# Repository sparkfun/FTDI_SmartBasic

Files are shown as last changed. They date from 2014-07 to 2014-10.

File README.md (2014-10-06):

FTDI_SmartBasic
===============
[FTDI SmartBasic  
*FTDI SmartBasic (DEV-12935)*](https://www.sparkfun.com/products/12935)

The FTDI SmartBasic uses a multiplexer to allow you to multiplex multiple serial 
devices into the hardware port on your Arduino Pro, Pro Mini, or other compatible 
board while still allowing you to program the board via the bootloader.

Repository Contents
-------------------
* **/Hardware** - All Eagle design files (.brd, .sch)
* **/Arduino** - All Arduino board examples
* **/Fritizing** - Fritzing part files
* **/Production** - Test bed files and production panel files

License Information
-------------------
The hardware is released under [Creative Commons Share-alike 3.0](http://creativecommons.org/licenses/by-sa/3.0/).  
All other code is open source so please feel free to do anything you want with it; yo

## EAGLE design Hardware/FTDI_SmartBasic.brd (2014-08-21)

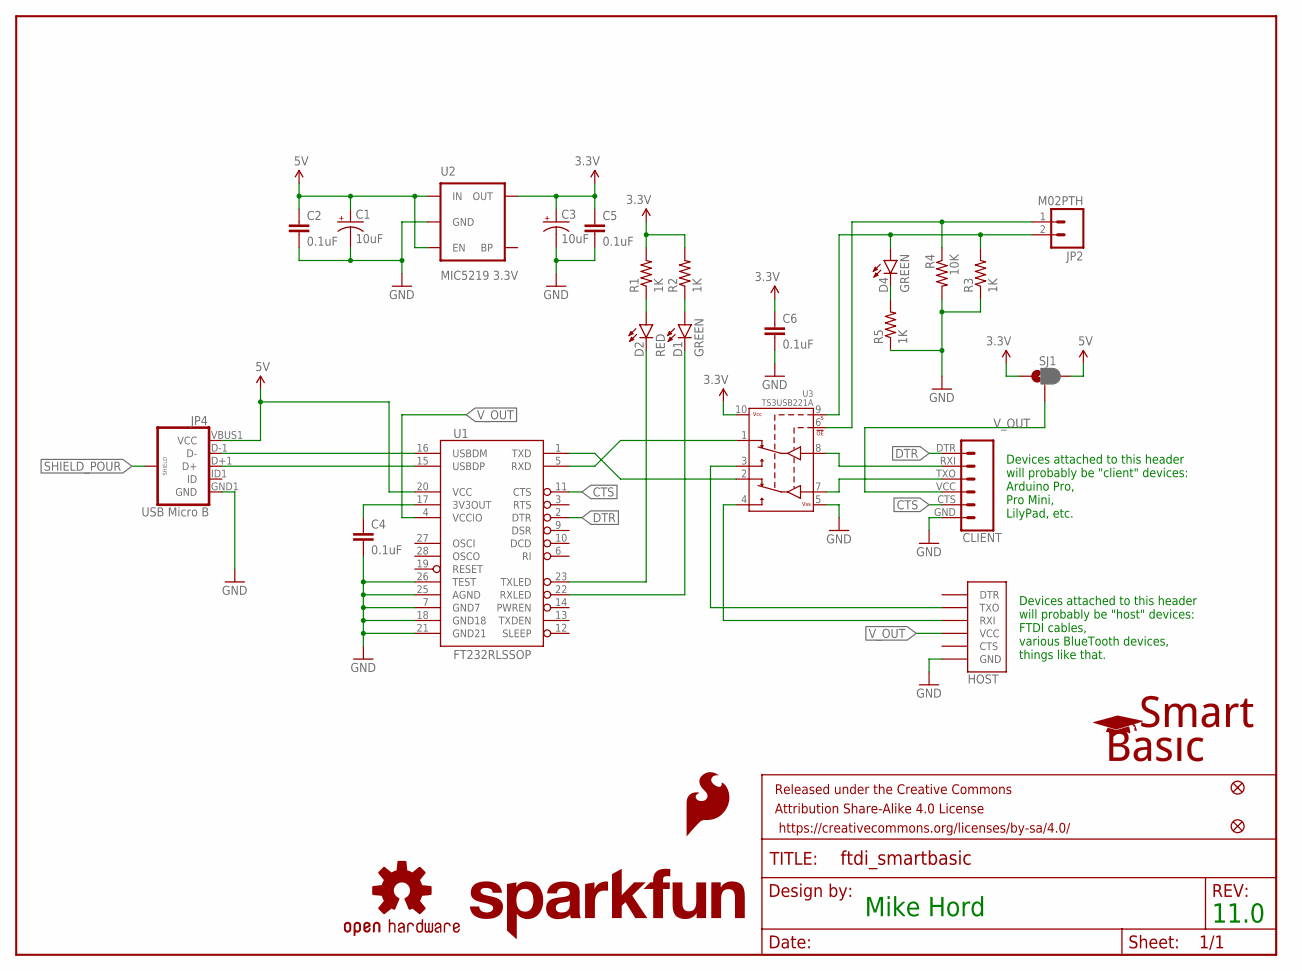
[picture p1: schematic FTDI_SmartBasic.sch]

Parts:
C1, C3: 10uF; EIA3216
C2, C4, C5, C6: 0.1uF; 0603-CAP
CLIENT: FTDI_BASICPTH; FTDI_BASIC
D1, D4: GREEN; LED-0603
D2: RED; LED-0603
FID1, FID2: FIDUCIAL1X2; FIDUCIAL-1X2
FRAME1: FRAME-LETTER; CREATIVE_COMMONS
HOST: FTDI_DEVICE; FTDI_DEVICE_SIDE
JP2: M02PTH; 1X02
JP4: USB Micro B; USB-B-MICRO-SMD_V03
LOGO1: SFE_LOGO_NAME.1_INCH; SFE_LOGO_NAME_.1
LOGO2: SFE_LOGO_FLAME.2_INCH; SFE_LOGO_FLAME_.2
LOGO3: OSHW-LOGOS; OSHW-LOGO-S
R1, R2, R3, R5: 1K; 0603-RES
R4: 10K; 0603-RES
SJ1: JUMPER-PAD-3-2OF3_NC_BY_PASTE; PAD-JUMPER-3-2OF3_NC_BY_PASTE_YES_SILK_FULL_BOX
U1: FT232RLSSOP; SSOP28DB
U2: MIC5219 3.3V; SOT23-5
U3: TS3USB221A; QFN-10-RSE
U$1: SMART_BASIC_LOGO

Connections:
3.3V: C3.A (+), C5.1, C6.1, R1.2, R2.2, SJ1.1, U2.5 (OUT), U3.10 (VCC)
5V: C1.A (+), C2.1, JP4.VBUS1 (VCC), SJ1.3, U1.20 (VCC), U2.1 (IN), U2.3 (EN)
!OE: JP2.1, R4.1, U3.6 (!OE)
CTS: CLIENT.CTS (5), U1.11 (CTS)
DTR: CLIENT.DTR (1), U1.2 (DTR)
GND: C1.C (-), C2.2, C3.C (-), C4.2, C5.2, C6.2, CLIENT.GND (6), HOST.P$6 (GND), JP4.GND1 (GND), R3.1, R4.2, R5.1, U1.7 (GND7), U1.18 (GND18), U1.21 (GND21), U1.25 (AGND), U1.26 (TEST), U2.2 (GND), U3.5 (VSS)
unnamed: JP4.D-1 (D-), U1.16 (USBDM)
unnamed: C4.1, U1.17 (3V3OUT)
unnamed: JP4.D+1 (D+), U1.15 (USBDP)
unnamed: D4.C, R5.2
unnamed: D2.A, R1.1
unnamed: D1.A, R2.1
unnamed: U1.5 (RXD), U3.1 (1D+)
unnamed: U1.1 (TXD), U3.2 (1D-)
unnamed: CLIENT.RXI (2), U3.8 (D+)
unnamed: CLIENT.TXO (3), U3.7 (D-)
unnamed: HOST.P$2 (TXO), U3.3 (2D+)
unnamed: HOST.P$3 (RXI), U3.4 (2D-)
RXLED: D1.C, U1.22 (RXLED)
SELECT: D4.A, JP2.2, R3.2, U3.9 (S)
SHIELD_POUR: JP4.SHIELD1 (SHIELD), JP4.SHIELD2 (SHIELD), JP4.SHIELD3 (SHIELD)
TXLED: D2.C, U1.23 (TXLED)
V_OUT: CLIENT.VCC (4), HOST.P$4 (VCC), SJ1.2, U1.4 (VCCIO)

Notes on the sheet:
Devices attached to this header will probably be "host" devices: FTDI cables, various BlueTooth devices, things like that.
Devices attached to this header will probably be "client" devices: Arduino Pro, Pro Mini, LilyPad, etc.
Mike Hord
11.0

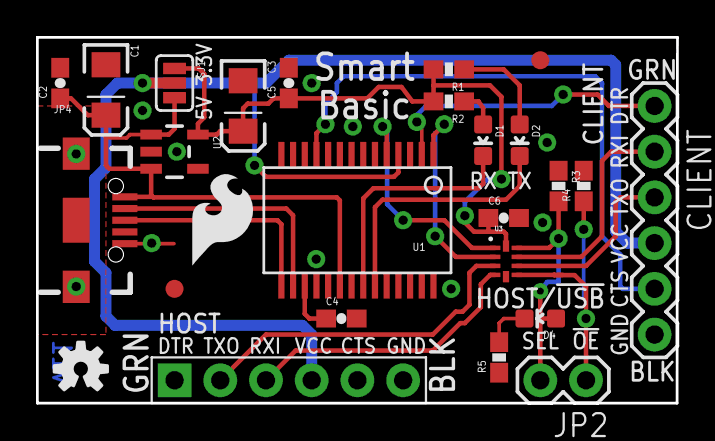
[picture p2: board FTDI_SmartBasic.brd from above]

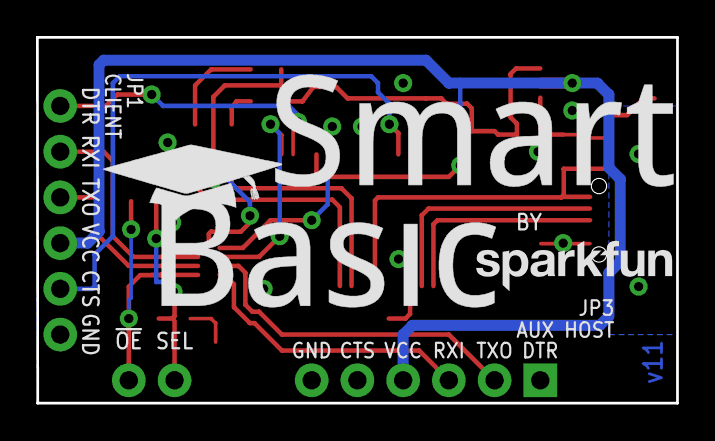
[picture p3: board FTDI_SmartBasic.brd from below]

Board: 2 copper layers, 35.6 x 20.3 mm, 29 parts (2 on the bottom side), 23 nets.

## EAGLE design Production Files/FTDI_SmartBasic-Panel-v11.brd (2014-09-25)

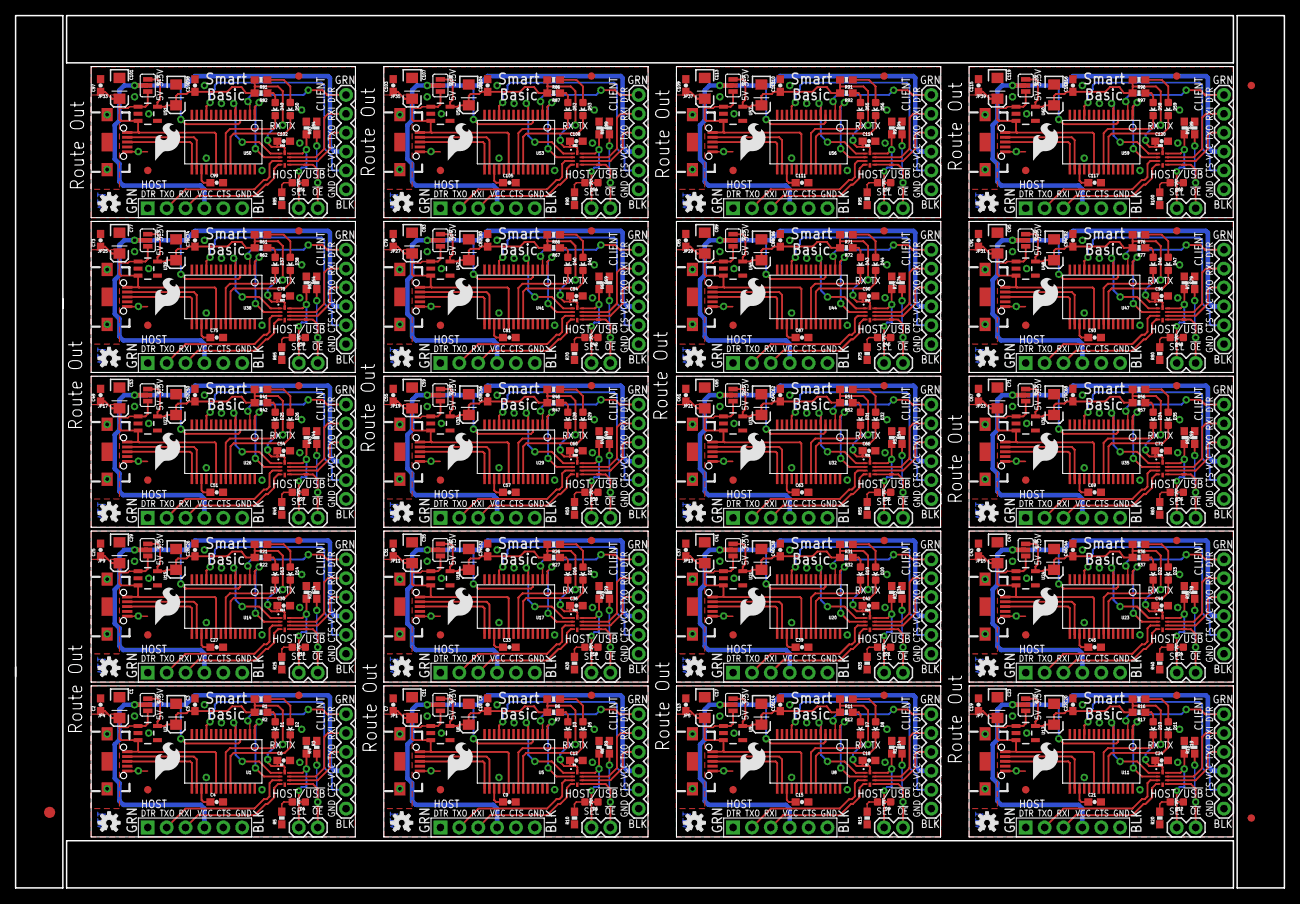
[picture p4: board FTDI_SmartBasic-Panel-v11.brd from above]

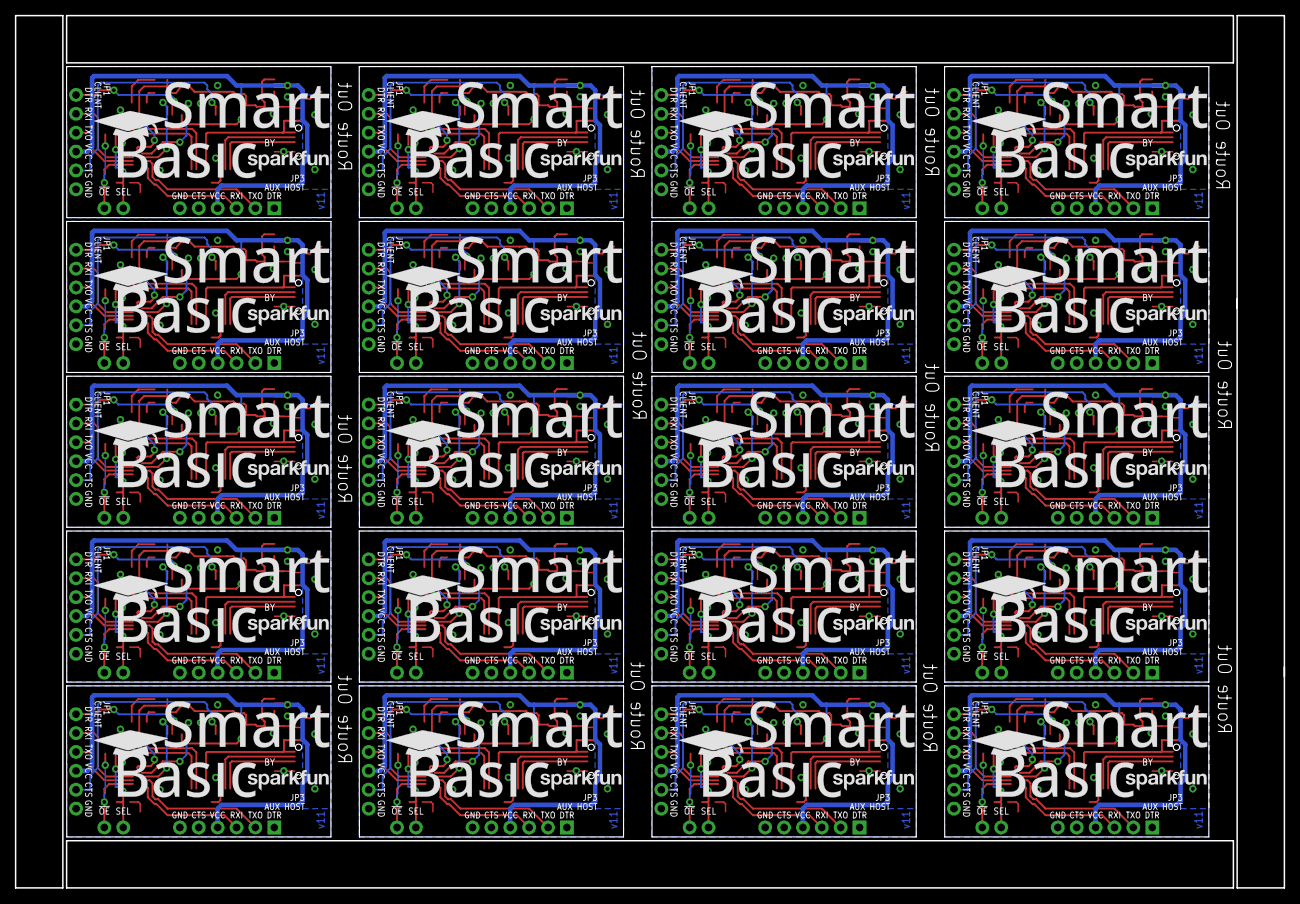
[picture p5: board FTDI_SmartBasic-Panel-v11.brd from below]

Board: 2 copper layers, 170.7 x 117.3 mm, 563 parts (40 on the bottom side), 460 nets.

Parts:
C1, C3, C8, C11, C14, C17, C20, C23, C26, C29, C32, C35, C38, C41, C44, C47, C50, C53, C56, C59, C62, C65, C68, C71, C74, C77, C80, C83, C86, C89, C92, C95, C98, C101, C104, C107, C110, C113, C116, C119: 10uF; EIA3216
C2, C4, C5, C6, C7, C9, C10, C12, C13, C15, C16, C18, C19, C21, C22, C24, C25, C27, C28, C30, C31, C33, C34, C36, C37, C39, C40, C42, C43, C45, C46, C48, C49, C51, C52, C54, C55, C57, C58, C60, C61, C63, C64, C66, C67, C69, C70, C72, C73, C75, C76, C78, C79, C81, C82, C84, C85, C87, C88, C90, C91, C93, C94, C96, C97, C99, C100, C102, C103, C105, C106, C108, C109, C111, C112, C114, C115, C117, C118, C120: 0.1uF; 0603-CAP
CLIENT, CLIENT1, CLIENT2, CLIENT3, CLIENT4, CLIENT5, CLIENT6, CLIENT7, CLIENT8, CLIENT9, CLIENT10, CLIENT11, CLIENT12, CLIENT13, CLIENT14, CLIENT15, CLIENT16, CLIENT17, CLIENT18, CLIENT19: FTDI_BASIC
D1, D3, D4, D6, D7, D9, D10, D12, D13, D15, D16, D18, D19, D21, D22, D24, D25, D27, D28, D30, D31, D33, D34, D36, D37, D39, D40, D42, D43, D45, D46, D48, D49, D51, D52, D54, D55, D57, D58, D60: GREEN; LED-0603
D2, D5, D8, D11, D14, D17, D20, D23, D26, D29, D32, D35, D38, D41, D44, D47, D50, D53, D56, D59: RED; LED-0603
E$1: FIDUCIAL-1.5X3
E$5, E$7: FIDUCIAL-1X2
FID1, FID2, FID3, FID4, FID5, FID6, FID7, FID8, FID9, FID10, FID11, FID12, FID13, FID14, FID15, FID16, FID17, FID18, FID19, FID20, FID21, FID22, FID23, FID24, FID25, FID26, FID27, FID28, FID29, FID30, FID31, FID32, FID33, FID34, FID35, FID36, FID37, FID38, FID39, FID40: FIDUCIAL1X2; FIDUCIAL-1X2
HOST, HOST1, HOST2, HOST3, HOST4, HOST5, HOST6, HOST7, HOST8, HOST9, HOST10, HOST11, HOST12, HOST13, HOST14, HOST15, HOST16, HOST17, HOST18, HOST19: FTDI_DEVICE_SIDE
JP1, JP4, JP5, JP7, JP9, JP11, JP13, JP15, JP17, JP19, JP21, JP23, JP25, JP27, JP29, JP31, JP33, JP35, JP37, JP39: USB Micro B; USB-B-MICRO-SMD_V03
JP2, JP3, JP6, JP8, JP10, JP12, JP14, JP16, JP18, JP20, JP22, JP24, JP26, JP28, JP30, JP32, JP34, JP36, JP38, JP40: M02PTH; 1X02
LOGO1, LOGO4, LOGO7, LOGO10, LOGO13, LOGO16, LOGO19, LOGO22, LOGO25, LOGO28, LOGO31, LOGO34, LOGO37, LOGO40, LOGO43, LOGO46, LOGO49, LOGO52, LOGO55, LOGO58: SFE_LOGO_NAME.1_INCH; SFE_LOGO_NAME_.1
LOGO2, LOGO6, LOGO9, LOGO12, LOGO15, LOGO18, LOGO21, LOGO24, LOGO27, LOGO30, LOGO33, LOGO36, LOGO39, LOGO42, LOGO45, LOGO48, LOGO51, LOGO54, LOGO57, LOGO60: SFE_LOGO_FLAME.2_INCH; SFE_LOGO_FLAME_.2
LOGO3, LOGO5, LOGO8, LOGO11, LOGO14, LOGO17, LOGO20, LOGO23, LOGO26, LOGO29, LOGO32, LOGO35, LOGO38, LOGO41, LOGO44, LOGO47, LOGO50, LOGO53, LOGO56, LOGO59: OSHW-LOGOS; OSHW-LOGO-S
R1, R2, R3, R5, R6, R7, R9, R10, R11, R12, R14, R15, R16, R17, R19, R20, R21, R22, R24, R25, R26, R27, R29, R30, R31, R32, R34, R35, R36, R37, R39, R40, R41, R42, R44, R45, R46, R47, R49, R50, R51, R52, R54, R55, R56, R57, R59, R60, R61, R62, R64, R65, R66, R67, R69, R70, R71, R72, R74, R75, R76, R77, R79, R80, R81, R82, R84, R85, R86, R87, R89, R90, R91, R92, R94, R95, R96, R97, R99, R100: 1K; 0603-RES
R4, R8, R13, R18, R23, R28, R33, R38, R43, R48, R53, R58, R63, R68, R73, R78, R83, R88, R93, R98: 10K; 0603-RES
SJ1, SJ2, SJ3, SJ4, SJ5, SJ6, SJ7, SJ8, SJ9, SJ10, SJ11, SJ12, SJ13, SJ14, SJ15, SJ16, SJ17, SJ18, SJ19, SJ20: JUMPER-PAD-3-2OF3_NC_BY_PASTE; PAD-JUMPER-3-2OF3_NC_BY_PASTE_YES_SILK_FULL_BOX
U1, U5, U8, U11, U14, U17, U20, U23, U26, U29, U32, U35, U38, U41, U44, U47, U50, U53, U56, U59: FT232RLSSOP; SSOP28DB
U2, U6, U9, U12, U15, U18, U21, U24, U27, U30, U33, U36, U39, U42, U45, U48, U51, U54, U57, U60: MIC5219 3.3V; SOT23-5
U3, U4, U7, U10, U13, U16, U19, U22, U25, U28, U31, U34, U37, U40, U43, U46, U49, U52, U55, U58: TS3USB221A; QFN-10-RSE
U$1, U$2, U$3, U$4, U$5, U$6, U$7, U$8, U$9, U$10, U$11, U$12, U$13, U$14, U$15, U$16, U$17, U$18, U$19, U$20: SMART_BASIC_LOGO

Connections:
3.3V: C3.A, C5.1, C6.1, R1.2, R2.2, SJ1.1, U2.5, U3.10
3.3V1: C8.A, C10.1, C12.1, R6.2, R7.2, SJ2.1, U4.10, U6.5
3.3V2: C14.A, C16.1, C18.1, R11.2, R12.2, SJ3.1, U7.10, U9.5
3.3V3: C20.A, C22.1, C24.1, R16.2, R17.2, SJ4.1, U10.10, U12.5
3.3V4: C26.A, C28.1, C30.1, R21.2, R22.2, SJ5.1, U13.10, U15.5
3.3V5: C32.A, C34.1, C36.1, R26.2, R27.2, SJ6.1, U16.10, U18.5
3.3V6: C38.A, C40.1, C42.1, R31.2, R32.2, SJ7.1, U19.10, U21.5
3.3V7: C44.A, C46.1, C48.1, R36.2, R37.2, SJ8.1, U22.10, U24.5
3.3V8: C50.A, C52.1, C54.1, R41.2, R42.2, SJ9.1, U25.10, U27.5
3.3V9: C56.A, C58.1, C60.1, R46.2, R47.2, SJ10.1, U28.10, U30.5
3.3V10: C62.A, C64.1, C66.1, R51.2, R52.2, SJ11.1, U31.10, U33.5
3.3V11: C68.A, C70.1, C72.1, R56.2, R57.2, SJ12.1, U34.10, U36.5
3.3V12: C74.A, C76.1, C78.1, R61.2, R62.2, SJ13.1, U37.10, U39.5
3.3V13: C80.A, C82.1, C84.1, R66.2, R67.2, SJ14.1, U40.10, U42.5
3.3V14: C86.A, C88.1, C90.1, R71.2, R72.2, SJ15.1, U43.10, U45.5
3.3V15: C92.A, C94.1, C96.1, R76.2, R77.2, SJ16.1, U46.10, U48.5
3.3V16: C98.A, C100.1, C102.1, R81.2, R82.2, SJ17.1, U49.10, U51.5
3.3V17: C104.A, C106.1, C108.1, R86.2, R87.2, SJ18.1, U52.10, U54.5
3.3V18: C110.A, C112.1, C114.1, R91.2, R92.2, SJ19.1, U55.10, U57.5
3.3V19: C116.A, C118.1, C120.1, R96.2, R97.2, SJ20.1, U58.10, U60.5
5V: C1.A, C2.1, JP4.VBUS1, SJ1.3, U1.20, U2.1, U2.3
5V1: C7.1, C11.A, JP1.VBUS1, SJ2.3, U5.20, U6.1, U6.3
5V2: C13.1, C17.A, JP5.VBUS1, SJ3.3, U8.20, U9.1, U9.3
5V3: C19.1, C23.A, JP7.VBUS1, SJ4.3, U11.20, U12.1, U12.3
5V4: C25.1, C29.A, JP9.VBUS1, SJ5.3, U14.20, U15.1, U15.3
5V5: C31.1, C35.A, JP11.VBUS1, SJ6.3, U17.20, U18.1, U18.3
5V6: C37.1, C41.A, JP13.VBUS1, SJ7.3, U20.20, U21.1, U21.3
5V7: C43.1, C47.A, JP15.VBUS1, SJ8.3, U23.20, U24.1, U24.3
5V8: C49.1, C53.A, JP17.VBUS1, SJ9.3, U26.20, U27.1, U27.3
5V9: C55.1, C59.A, JP19.VBUS1, SJ10.3, U29.20, U30.1, U30.3
5V10: C61.1, C65.A, JP21.VBUS1, SJ11.3, U32.20, U33.1, U33.3
5V11: C67.1, C71.A, JP23.VBUS1, SJ12.3, U35.20, U36.1, U36.3
5V12: C73.1, C77.A, JP25.VBUS1, SJ13.3, U38.20, U39.1, U39.3
5V13: C79.1, C83.A, JP27.VBUS1, SJ14.3, U41.20, U42.1, U42.3
5V14: C85.1, C89.A, JP29.VBUS1, SJ15.3, U44.20, U45.1, U45.3
5V15: C91.1, C95.A, JP31.VBUS1, SJ16.3, U47.20, U48.1, U48.3
5V16: C97.1, C101.A, JP33.VBUS1, SJ17.3, U50.20, U51.1, U51.3
5V17: C103.1, C107.A, JP35.VBUS1, SJ18.3, U53.20, U54.1, U54.3
5V18: C109.1, C113.A, JP37.VBUS1, SJ19.3, U56.20, U57.1, U57.3
5V19: C115.1, C119.A, JP39.VBUS1, SJ20.3, U59.20, U60.1, U60.3
!OE: JP2.1, R4.1, U3.6
!OE1: JP3.1, R8.1, U4.6
!OE2: JP6.1, R13.1, U7.6
!OE3: JP8.1, R18.1, U10.6
!OE4: JP10.1, R23.1, U13.6
!OE5: JP12.1, R28.1, U16.6
!OE6: JP14.1, R33.1, U19.6
!OE7: JP16.1, R38.1, U22.6
!OE8: JP18.1, R43.1, U25.6
!OE9: JP20.1, R48.1, U28.6
!OE10: JP22.1, R53.1, U31.6
!OE11: JP24.1, R58.1, U34.6
!OE12: JP26.1, R63.1, U37.6
!OE13: JP28.1, R68.1, U40.6
!OE14: JP30.1, R73.1, U43.6
!OE15: JP32.1, R78.1, U46.6
!OE16: JP34.1, R83.1, U49.6
!OE17: JP36.1, R88.1, U52.6
!OE18: JP38.1, R93.1, U55.6
!OE19: JP40.1, R98.1, U58.6
CTS: CLIENT.CTS, U1.11
CTS1: CLIENT1.CTS, U5.11
CTS2: CLIENT2.CTS, U8.11
CTS3: CLIENT3.CTS, U11.11
CTS4: CLIENT4.CTS, U14.11
CTS5: CLIENT5.CTS, U17.11
CTS6: CLIENT6.CTS, U20.11
CTS7: CLIENT7.CTS, U23.11
CTS8: CLIENT8.CTS, U26.11
CTS9: CLIENT9.CTS, U29.11
CTS10: CLIENT10.CTS, U32.11
CTS11: CLIENT11.CTS, U35.11
CTS12: CLIENT12.CTS, U38.11
CTS13: CLIENT13.CTS, U41.11
CTS14: CLIENT14.CTS, U44.11
CTS15: CLIENT15.CTS, U47.11
CTS16: CLIENT16.CTS, U50.11
CTS17: CLIENT17.CTS, U53.11
CTS18: CLIENT18.CTS, U56.11
CTS19: CLIENT19.CTS, U59.11
DTR: CLIENT.DTR, U1.2
DTR1: CLIENT1.DTR, U5.2
DTR2: CLIENT2.DTR, U8.2
DTR3: CLIENT3.DTR, U11.2
DTR4: CLIENT4.DTR, U14.2
DTR5: CLIENT5.DTR, U17.2
DTR6: CLIENT6.DTR, U20.2
DTR7: CLIENT7.DTR, U23.2
DTR8: CLIENT8.DTR, U26.2
DTR9: CLIENT9.DTR, U29.2
DTR10: CLIENT10.DTR, U32.2
DTR11: CLIENT11.DTR, U35.2
DTR12: CLIENT12.DTR, U38.2
DTR13: CLIENT13.DTR, U41.2
DTR14: CLIENT14.DTR, U44.2
DTR15: CLIENT15.DTR, U47.2
DTR16: CLIENT16.DTR, U50.2
DTR17: CLIENT17.DTR, U53.2
DTR18: CLIENT18.DTR, U56.2
DTR19: CLIENT19.DTR, U59.2
GND: C1.C, C2.2, C3.C, C4.2, C5.2, C6.2, CLIENT.GND, HOST.P$6, JP4.GND1, R3.1, R4.2, R5.1, U1.7, U1.18, U1.21, U1.25, U1.26, U2.2, U3.5
GND1: C7.2, C8.C, C9.2, C10.2, C11.C, C12.2, CLIENT1.GND, HOST1.P$6, JP1.GND1, R8.2, R9.1, R10.1, U4.5, U5.7, U5.18, U5.21, U5.25, U5.26, U6.2
GND2: C13.2, C14.C, C15.2, C16.2, C17.C, C18.2, CLIENT2.GND, HOST2.P$6, JP5.GND1, R13.2, R14.1, R15.1, U7.5, U8.7, U8.18, U8.21, U8.25, U8.26, U9.2
GND3: C19.2, C20.C, C21.2, C22.2, C23.C, C24.2, CLIENT3.GND, HOST3.P$6, JP7.GND1, R18.2, R19.1, R20.1, U10.5, U11.7, U11.18, U11.21, U11.25, U11.26, U12.2
GND4: C25.2, C26.C, C27.2, C28.2, C29.C, C30.2, CLIENT4.GND, HOST4.P$6, JP9.GND1, R23.2, R24.1, R25.1, U13.5, U14.7, U14.18, U14.21, U14.25, U14.26, U15.2
GND5: C31.2, C32.C, C33.2, C34.2, C35.C, C36.2, CLIENT5.GND, HOST5.P$6, JP11.GND1, R28.2, R29.1, R30.1, U16.5, U17.7, U17.18, U17.21, U17.25, U17.26, U18.2
GND6: C37.2, C38.C, C39.2, C40.2, C41.C, C42.2, CLIENT6.GND, HOST6.P$6, JP13.GND1, R33.2, R34.1, R35.1, U19.5, U20.7, U20.18, U20.21, U20.25, U20.26, U21.2
GND7: C43.2, C44.C, C45.2, C46.2, C47.C, C48.2, CLIENT7.GND, HOST7.P$6, JP15.GND1, R38.2, R39.1, R40.1, U22.5, U23.7, U23.18, U23.21, U23.25, U23.26, U24.2
GND8: C49.2, C50.C, C51.2, C52.2, C53.C, C54.2, CLIENT8.GND, HOST8.P$6, JP17.GND1, R43.2, R44.1, R45.1, U25.5, U26.7, U26.18, U26.21, U26.25, U26.26, U27.2
GND9: C55.2, C56.C, C57.2, C58.2, C59.C, C60.2, CLIENT9.GND, HOST9.P$6, JP19.GND1, R48.2, R49.1, R50.1, U28.5, U29.7, U29.18, U29.21, U29.25, U29.26, U30.2
GND10: C61.2, C62.C, C63.2, C64.2, C65.C, C66.2, CLIENT10.GND, HOST10.P$6, JP21.GND1, R53.2, R54.1, R55.1, U31.5, U32.7, U32.18, U32.21, U32.25, U32.26, U33.2
GND11: C67.2, C68.C, C69.2, C70.2, C71.C, C72.2, CLIENT11.GND, HOST11.P$6, JP23.GND1, R58.2, R59.1, R60.1, U34.5, U35.7, U35.18, U35.21, U35.25, U35.26, U36.2
GND12: C73.2, C74.C, C75.2, C76.2, C77.C, C78.2, CLIENT12.GND, HOST12.P$6, JP25.GND1, R63.2, R64.1, R65.1, U37.5, U38.7, U38.18, U38.21, U38.25, U38.26, U39.2
GND13: C79.2, C80.C, C81.2, C82.2, C83.C, C84.2, CLIENT13.GND, HOST13.P$6, JP27.GND1, R68.2, R69.1, R70.1, U40.5, U41.7, U41.18, U41.21, U41.25, U41.26, U42.2
GND14: C85.2, C86.C, C87.2, C88.2, C89.C, C90.2, CLIENT14.GND, HOST14.P$6, JP29.GND1, R73.2, R74.1, R75.1, U43.5, U44.7, U44.18, U44.21, U44.25, U44.26, U45.2
GND15: C91.2, C92.C, C93.2, C94.2, C95.C, C96.2, CLIENT15.GND, HOST15.P$6, JP31.GND1, R78.2, R79.1, R80.1, U46.5, U47.7, U47.18, U47.21, U47.25, U47.26, U48.2
GND16: C97.2, C98.C, C99.2, C100.2, C101.C, C102.2, CLIENT16.GND, HOST16.P$6, JP33.GND1, R83.2, R84.1, R85.1, U49.5, U50.7, U50.18, U50.21, U50.25, U50.26, U51.2
GND17: C103.2, C104.C, C105.2, C106.2, C107.C, C108.2, CLIENT17.GND, HOST17.P$6, JP35.GND1, R88.2, R89.1, R90.1, U52.5, U53.7, U53.18, U53.21, U53.25, U53.26, U54.2
GND18: C109.2, C110.C, C111.2, C112.2, C113.C, C114.2, CLIENT18.GND, HOST18.P$6, JP37.GND1, R93.2, R94.1, R95.1, U55.5, U56.7, U56.18, U56.21, U56.25, U56.26, U57.2
GND19: C115.2, C116.C, C117.2, C118.2, C119.C, C120.2, CLIENT19.GND, HOST19.P$6, JP39.GND1, R98.2, R99.1, R100.1, U58.5, U59.7, U59.18, U59.21, U59.25, U59.26, U60.2
unnamed: JP4.D-1, U1.16
unnamed: C4.1, U1.17
unnamed: JP4.D+1, U1.15
unnamed: D4.C, R5.2
unnamed: D2.A, R1.1
unnamed: D1.A, R2.1
unnamed: JP1.D-1, U5.16
unnamed: JP1.D+1, U5.15
unnamed: D5.A, R6.1
unnamed: D3.A, R7.1
unnamed: U1.5, U3.1
unnamed: U1.1, U3.2
unnamed: CLIENT.RXI, U3.8
unnamed: CLIENT.TXO, U3.7
unnamed: CLIENT1.RXI, U4.8
unnamed: HOST.P$2, U3.3
unnamed: HOST.P$3, U3.4
unnamed: CLIENT1.TXO, U4.7
unnamed: U4.1, U5.5
unnamed: U4.2, U5.1
unnamed: HOST1.P$2, U4.3
unnamed: HOST1.P$3, U4.4
unnamed: C9.1, U5.17
unnamed: D6.C, R10.2
unnamed: JP5.D-1, U8.16
unnamed: JP5.D+1, U8.15
unnamed: D8.A, R11.1
unnamed: D7.A, R12.1
unnamed: CLIENT2.RXI, U7.8
unnamed: CLIENT2.TXO, U7.7
unnamed: U7.1, U8.5
unnamed: U7.2, U8.1
unnamed: HOST2.P$2, U7.3
unnamed: HOST2.P$3, U7.4
unnamed: C15.1, U8.17
unnamed: D9.C, R15.2
unnamed: JP7.D-1, U11.16
unnamed: JP7.D+1, U11.15
unnamed: D11.A, R16.1
unnamed: D10.A, R17.1
unnamed: CLIENT3.RXI, U10.8
unnamed: CLIENT3.TXO, U10.7
unnamed: U10.1, U11.5
unnamed: U10.2, U11.1
unnamed: HOST3.P$2, U10.3
unnamed: HOST3.P$3, U10.4
unnamed: C21.1, U11.17
unnamed: D12.C, R20.2
unnamed: JP9.D-1, U14.16
unnamed: JP9.D+1, U14.15
unnamed: D14.A, R21.1
unnamed: D13.A, R22.1
unnamed: CLIENT4.RXI, U13.8
unnamed: CLIENT4.TXO, U13.7
unnamed: U13.1, U14.5
unnamed: U13.2, U14.1
unnamed: HOST4.P$2, U13.3
unnamed: HOST4.P$3, U13.4
unnamed: C27.1, U14.17
unnamed: D15.C, R25.2
unnamed: JP11.D-1, U17.16
unnamed: JP11.D+1, U17.15
unnamed: D17.A, R26.1
unnamed: D16.A, R27.1
unnamed: CLIENT5.RXI, U16.8
unnamed: CLIENT5.TXO, U16.7
unnamed: U16.1, U17.5
unnamed: U16.2, U17.1
unnamed: HOST5.P$2, U16.3
unnamed: HOST5.P$3, U16.4
unnamed: C33.1, U17.17
unnamed: D18.C, R30.2
unnamed: JP13.D-1, U20.16
unnamed: JP13.D+1, U20.15
unnamed: D20.A, R31.1
unnamed: D19.A, R32.1
unnamed: CLIENT6.RXI, U19.8
unnamed: CLIENT6.TXO, U19.7
unnamed: U19.1, U20.5
unnamed: U19.2, U20.1
unnamed: HOST6.P$2, U19.3
unnamed: HOST6.P$3, U19.4
unnamed: C39.1, U20.17
unnamed: D21.C, R35.2
unnamed: JP15.D-1, U23.16
unnamed: JP15.D+1, U23.15
unnamed: D23.A, R36.1
unnamed: D22.A, R37.1
unnamed: CLIENT7.RXI, U22.8
unnamed: CLIENT7.TXO, U22.7
unnamed: U22.1, U23.5
unnamed: U22.2, U23.1
unnamed: HOST7.P$2, U22.3
unnamed: HOST7.P$3, U22.4
unnamed: C45.1, U23.17
unnamed: D24.C, R40.2
unnamed: JP17.D-1, U26.16
unnamed: JP17.D+1, U26.15
unnamed: D26.A, R41.1
unnamed: D25.A, R42.1
unnamed: CLIENT8.RXI, U25.8
unnamed: CLIENT8.TXO, U25.7
unnamed: U25.1, U26.5
unnamed: U25.2, U26.1
unnamed: HOST8.P$2, U25.3
unnamed: HOST8.P$3, U25.4
unnamed: C51.1, U26.17
unnamed: D27.C, R45.2
unnamed: JP19.D-1, U29.16
unnamed: JP19.D+1, U29.15
unnamed: D29.A, R46.1
unnamed: D28.A, R47.1
unnamed: CLIENT9.RXI, U28.8
unnamed: CLIENT9.TXO, U28.7
unnamed: U28.1, U29.5
unnamed: U28.2, U29.1
unnamed: HOST9.P$2, U28.3
unnamed: HOST9.P$3, U28.4
unnamed: C57.1, U29.17
unnamed: D30.C, R50.2
unnamed: JP21.D-1, U32.16
unnamed: JP21.D+1, U32.15
unnamed: D32.A, R51.1
unnamed: D31.A, R52.1
unnamed: CLIENT10.RXI, U31.8
unnamed: CLIENT10.TXO, U31.7
unnamed: U31.1, U32.5
unnamed: U31.2, U32.1
unnamed: HOST10.P$2, U31.3
unnamed: HOST10.P$3, U31.4
unnamed: C63.1, U32.17
unnamed: D33.C, R55.2
unnamed: JP23.D-1, U35.16
unnamed: JP23.D+1, U35.15
unnamed: D35.A, R56.1
unnamed: D34.A, R57.1
unnamed: CLIENT11.RXI, U34.8
unnamed: CLIENT11.TXO, U34.7
unnamed: U34.1, U35.5
unnamed: U34.2, U35.1
unnamed: HOST11.P$2, U34.3
unnamed: HOST11.P$3, U34.4
unnamed: C69.1, U35.17
unnamed: D36.C, R60.2
unnamed: JP25.D-1, U38.16
unnamed: JP25.D+1, U38.15
unnamed: D38.A, R61.1
unnamed: D37.A, R62.1
unnamed: CLIENT12.RXI, U37.8
unnamed: CLIENT12.TXO, U37.7
unnamed: U37.1, U38.5
unnamed: U37.2, U38.1
unnamed: HOST12.P$2, U37.3
unnamed: HOST12.P$3, U37.4
unnamed: C75.1, U38.17
unnamed: D39.C, R65.2
unnamed: JP27.D-1, U41.16
unnamed: JP27.D+1, U41.15
unnamed: D41.A, R66.1
unnamed: D40.A, R67.1
unnamed: CLIENT13.RXI, U40.8
unnamed: CLIENT13.TXO, U40.7
unnamed: U40.1, U41.5
unnamed: U40.2, U41.1
unnamed: HOST13.P$2, U40.3
unnamed: HOST13.P$3, U40.4
unnamed: C81.1, U41.17
unnamed: D42.C, R70.2
unnamed: JP29.D-1, U44.16
unnamed: JP29.D+1, U44.15
unnamed: D44.A, R71.1
unnamed: D43.A, R72.1
unnamed: CLIENT14.RXI, U43.8
unnamed: CLIENT14.TXO, U43.7
unnamed: U43.1, U44.5
unnamed: U43.2, U44.1
unnamed: HOST14.P$2, U43.3
unnamed: HOST14.P$3, U43.4
unnamed: C87.1, U44.17
unnamed: D45.C, R75.2
unnamed: JP31.D-1, U47.16
unnamed: JP31.D+1, U47.15
unnamed: D47.A, R76.1
unnamed: D46.A, R77.1
unnamed: CLIENT15.RXI, U46.8
unnamed: CLIENT15.TXO, U46.7
unnamed: U46.1, U47.5
unnamed: U46.2, U47.1
unnamed: HOST15.P$2, U46.3
unnamed: HOST15.P$3, U46.4
unnamed: C93.1, U47.17
unnamed: D48.C, R80.2
unnamed: JP33.D-1, U50.16
unnamed: JP33.D+1, U50.15
unnamed: D50.A, R81.1
unnamed: D49.A, R82.1
unnamed: CLIENT16.RXI, U49.8
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

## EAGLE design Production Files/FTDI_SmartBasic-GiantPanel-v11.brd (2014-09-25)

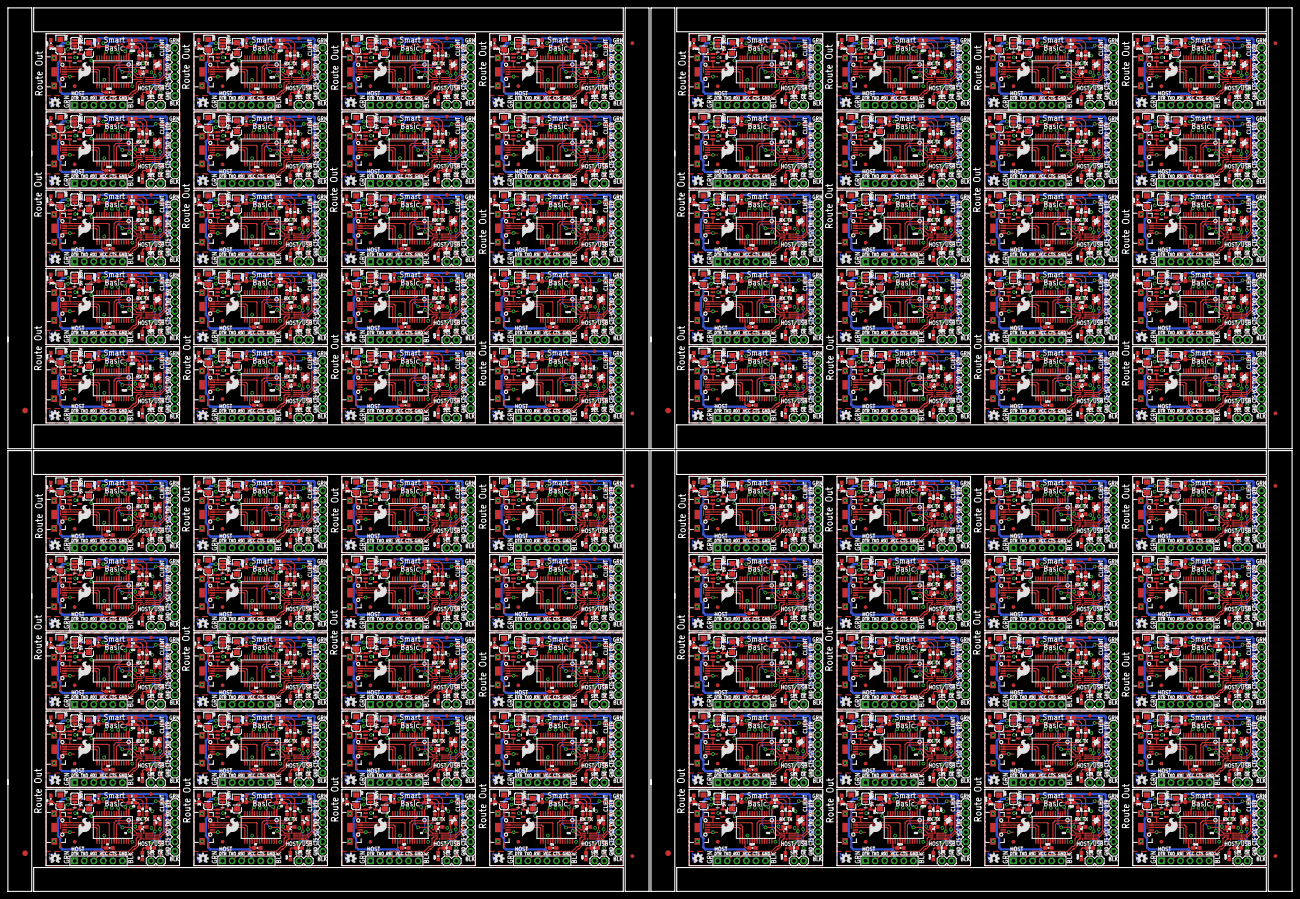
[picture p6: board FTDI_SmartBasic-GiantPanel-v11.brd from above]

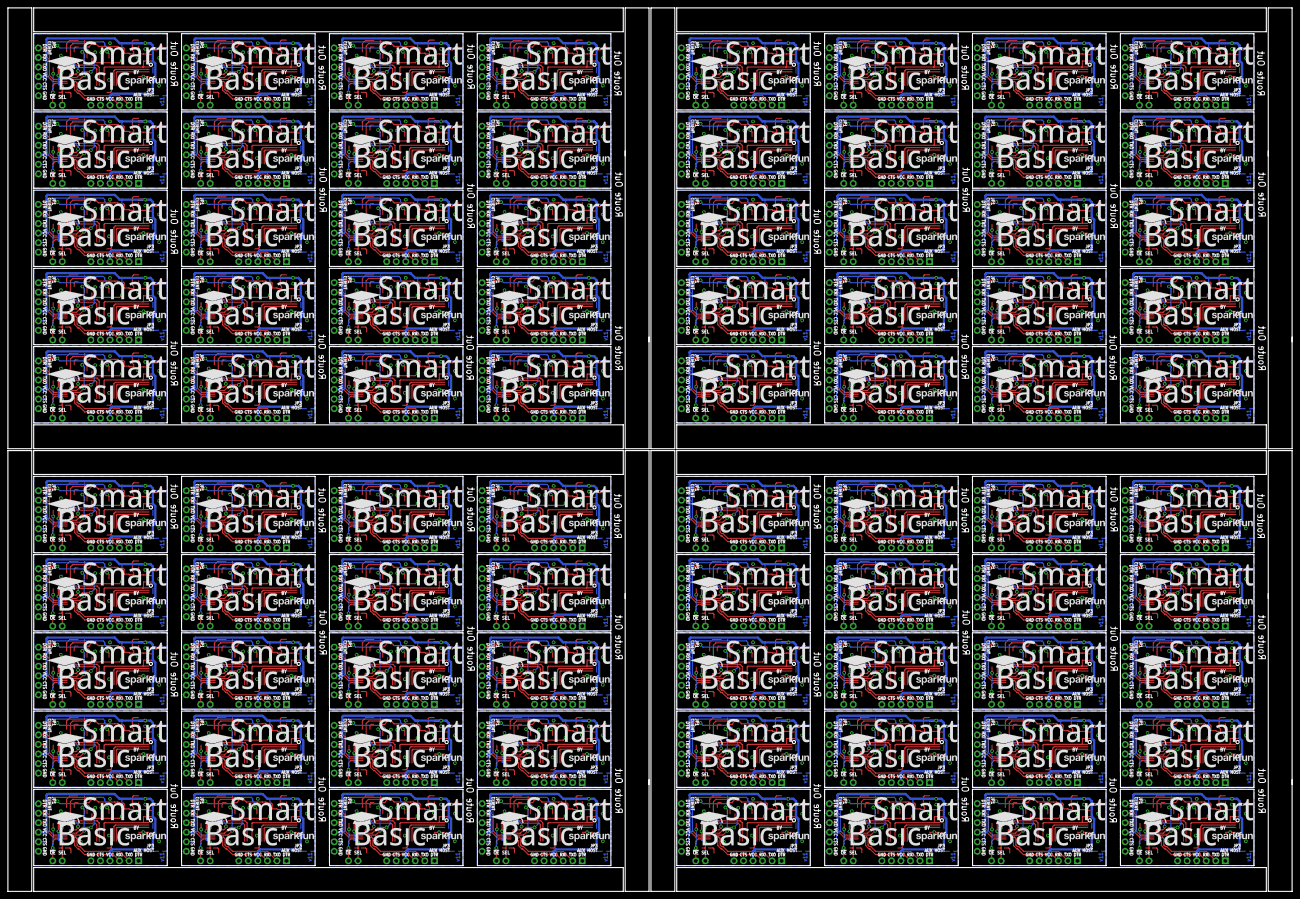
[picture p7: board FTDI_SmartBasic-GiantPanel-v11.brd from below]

Board: 2 copper layers, 341.9 x 235.2 mm, 2252 parts (160 on the bottom side), 1840 nets.

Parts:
C1, C3, C8, C11, C14, C17, C20, C23, C26, C29, C32, C35, C38, C41, C44, C47, C50, C53, C56, C59, C62, C65, C68, C71, C74, C77, C80, C83, C86, C89, C92, C95, C98, C101, C104, C107, C110, C113, C116, C119, C122, C125, C128, C131, C134, C137, C140, C143, C146, C149, C152, C155, C158, C161, C164, C167, C170, C173, C176, C179, C182, C185, C188, C191, C194, C197, C200, C203, C206, C209, C212, C215, C218, C221, C224, C227, C230, C233, C236, C239, C242, C245, C248, C251, C254, C257, C260, C263, C266, C269, C272, C275, C278, C281, C284, C287, C290, C293, C296, C299, C302, C305, C308, C311, C314, C317, C320, C323, C326, C329, C332, C335, C338, C341, C344, C347, C350, C353, C356, C359, C362, C365, C368, C371, C374, C377, C380, C383, C386, C389, C392, C395, C398, C401, C404, C407, C410, C413, C416, C419, C422, C425, C428, C431, C434, C437, C440, C443, C446, C449, C452, C455, C458, C461, C464, C467, C470, C473, C476, C479: 10uF; EIA3216
C2, C4, C5, C6, C7, C9, C10, C12, C13, C15, C16, C18, C19, C21, C22, C24, C25, C27, C28, C30, C31, C33, C34, C36, C37, C39, C40, C42, C43, C45, C46, C48, C49, C51, C52, C54, C55, C57, C58, C60, C61, C63, C64, C66, C67, C69, C70, C72, C73, C75, C76, C78, C79, C81, C82, C84, C85, C87, C88, C90, C91, C93, C94, C96, C97, C99, C100, C102, C103, C105, C106, C108, C109, C111, C112, C114, C115, C117, C118, C120, C121, C123, C124, C126, C127, C129, C130, C132, C133, C135, C136, C138, C139, C141, C142, C144, C145, C147, C148, C150, C151, C153, C154, C156, C157, C159, C160, C162, C163, C165, C166, C168, C169, C171, C172, C174, C175, C177, C178, C180, C181, C183, C184, C186, C187, C189, C190, C192, C193, C195, C196, C198, C199, C201, C202, C204, C205, C207, C208, C210, C211, C213, C214, C216, C217, C219, C220, C222, C223, C225, C226, C228, C229, C231, C232, C234, C235, C237, C238, C240, C241, C243, C244, C246, C247, C249, C250, C252, C253, C255, C256, C258, C259, C261, C262, C264, C265, C267, C268, C270, C271, C273, C274, C276, C277, C279, C280, C282, C283, C285, C286, C288, C289, C291, C292, C294, C295, C297, C298, C300, C301, C303, C304, C306, C307, C309, C310, C312, C313, C315, C316, C318, C319, C321, C322, C324, C325, C327, C328, C330, C331, C333, C334, C336, C337, C339, C340, C342, C343, C345, C346, C348, C349, C351, C352, C354, C355, C357, C358, C360, C361, C363, C364, C366, C367, C369, C370, C372, C373, C375, C376, C378, C379, C381, C382, C384, C385, C387, C388, C390, C391, C393, C394, C396, C397, C399, C400, C402, C403, C405, C406, C408, C409, C411, C412, C414, C415, C417, C418, C420, C421, C423, C424, C426, C427, C429, C430, C432, C433, C435, C436, C438, C439, C441, C442, C444, C445, C447, C448, C450, C451, C453, C454, C456, C457, C459, C460, C462, C463, C465, C466, C468, C469, C471, C472, C474, C475, C477, C478, C480: 0.1uF; 0603-CAP
CLIENT, CLIENT1, CLIENT2, CLIENT3, CLIENT4, CLIENT5, CLIENT6, CLIENT7, CLIENT8, CLIENT9, CLIENT10, CLIENT11, CLIENT12, CLIENT13, CLIENT14, CLIENT15, CLIENT16, CLIENT17, CLIENT18, CLIENT19, CLIENT20, CLIENT21, CLIENT22, CLIENT23, CLIENT24, CLIENT25, CLIENT26, CLIENT27, CLIENT28, CLIENT29, CLIENT30, CLIENT31, CLIENT32, CLIENT33, CLIENT34, CLIENT35, CLIENT36, CLIENT37, CLIENT38, CLIENT39, CLIENT40, CLIENT41, CLIENT42, CLIENT43, CLIENT44, CLIENT45, CLIENT46, CLIENT47, CLIENT48, CLIENT49, CLIENT50, CLIENT51, CLIENT52, CLIENT53, CLIENT54, CLIENT55, CLIENT56, CLIENT57, CLIENT58, CLIENT59, CLIENT60, CLIENT61, CLIENT62, CLIENT63, CLIENT64, CLIENT65, CLIENT66, CLIENT67, CLIENT68, CLIENT69, CLIENT70, CLIENT71, CLIENT72, CLIENT73, CLIENT74, CLIENT75, CLIENT76, CLIENT77, CLIENT78, CLIENT79: FTDI_BASIC
D1, D3, D4, D6, D7, D9, D10, D12, D13, D15, D16, D18, D19, D21, D22, D24, D25, D27, D28, D30, D31, D33, D34, D36, D37, D39, D40, D42, D43, D45, D46, D48, D49, D51, D52, D54, D55, D57, D58, D60, D61, D63, D64, D66, D67, D69, D70, D72, D73, D75, D76, D78, D79, D81, D82, D84, D85, D87, D88, D90, D91, D93, D94, D96, D97, D99, D100, D102, D103, D105, D106, D108, D109, D111, D112, D114, D115, D117, D118, D120, D121, D123, D124, D126, D127, D129, D130, D132, D133, D135, D136, D138, D139, D141, D142, D144, D145, D147, D148, D150, D151, D153, D154, D156, D157, D159, D160, D162, D163, D165, D166, D168, D169, D171, D172, D174, D175, D177, D178, D180, D181, D183, D184, D186, D187, D189, D190, D192, D193, D195, D196, D198, D199, D201, D202, D204, D205, D207, D208, D210, D211, D213, D214, D216, D217, D219, D220, D222, D223, D225, D226, D228, D229, D231, D232, D234, D235, D237, D238, D240: GREEN; LED-0603
D2, D5, D8, D11, D14, D17, D20, D23, D26, D29, D32, D35, D38, D41, D44, D47, D50, D53, D56, D59, D62, D65, D68, D71, D74, D77, D80, D83, D86, D89, D92, D95, D98, D101, D104, D107, D110, D113, D116, D119, D122, D125, D128, D131, D134, D137, D140, D143, D146, D149, D152, D155, D158, D161, D164, D167, D170, D173, D176, D179, D182, D185, D188, D191, D194, D197, D200, D203, D206, D209, D212, D215, D218, D221, D224, D227, D230, D233, D236, D239: RED; LED-0603
E$1, E$4, E$9, E$12: FIDUCIAL-1.5X3
E$2, E$3, E$5, E$6, E$7, E$8, E$10, E$11: FIDUCIAL-1X2
FID1, FID2, FID3, FID4, FID5, FID6, FID7, FID8, FID9, FID10, FID11, FID12, FID13, FID14, FID15, FID16, FID17, FID18, FID19, FID20, FID21, FID22, FID23, FID24, FID25, FID26, FID27, FID28, FID29, FID30, FID31, FID32, FID33, FID34, FID35, FID36, FID37, FID38, FID39, FID40, FID41, FID42, FID43, FID44, FID45, FID46, FID47, FID48, FID49, FID50, FID51, FID52, FID53, FID54, FID55, FID56, FID57, FID58, FID59, FID60, FID61, FID62, FID63, FID64, FID65, FID66, FID67, FID68, FID69, FID70, FID71, FID72, FID73, FID74, FID75, FID76, FID77, FID78, FID79, FID80, FID81, FID82, FID83, FID84, FID85, FID86, FID87, FID88, FID89, FID90, FID91, FID92, FID93, FID94, FID95, FID96, FID97, FID98, FID99, FID100, FID101, FID102, FID103, FID104, FID105, FID106, FID107, FID108, FID109, FID110, FID111, FID112, FID113, FID114, FID115, FID116, FID117, FID118, FID119, FID120, FID121, FID122, FID123, FID124, FID125, FID126, FID127, FID128, FID129, FID130, FID131, FID132, FID133, FID134, FID135, FID136, FID137, FID138, FID139, FID140, FID141, FID142, FID143, FID144, FID145, FID146, FID147, FID148, FID149, FID150, FID151, FID152, FID153, FID154, FID155, FID156, FID157, FID158, FID159, FID160: FIDUCIAL1X2; FIDUCIAL-1X2
HOST, HOST1, HOST2, HOST3, HOST4, HOST5, HOST6, HOST7, HOST8, HOST9, HOST10, HOST11, HOST12, HOST13, HOST14, HOST15, HOST16, HOST17, HOST18, HOST19, HOST20, HOST21, HOST22, HOST23, HOST24, HOST25, HOST26, HOST27, HOST28, HOST29, HOST30, HOST31, HOST32, HOST33, HOST34, HOST35, HOST36, HOST37, HOST38, HOST39, HOST40, HOST41, HOST42, HOST43, HOST44, HOST45, HOST46, HOST47, HOST48, HOST49, HOST50, HOST51, HOST52, HOST53, HOST54, HOST55, HOST56, HOST57, HOST58, HOST59, HOST60, HOST61, HOST62, HOST63, HOST64, HOST65, HOST66, HOST67, HOST68, HOST69, HOST70, HOST71, HOST72, HOST73, HOST74, HOST75, HOST76, HOST77, HOST78, HOST79: FTDI_DEVICE_SIDE
JP1, JP4, JP5, JP7, JP9, JP11, JP13, JP15, JP17, JP19, JP21, JP23, JP25, JP27, JP29, JP31, JP33, JP35, JP37, JP39, JP41, JP43, JP45, JP47, JP49, JP51, JP53, JP55, JP57, JP59, JP61, JP63, JP65, JP67, JP69, JP71, JP73, JP75, JP77, JP79, JP81, JP83, JP85, JP87, JP89, JP91, JP93, JP95, JP97, JP99, JP101, JP103, JP105, JP107, JP109, JP111, JP113, JP115, JP117, JP119, JP121, JP123, JP125, JP127, JP129, JP131, JP133, JP135, JP137, JP139, JP141, JP143, JP145, JP147, JP149, JP151, JP153, JP155, JP157, JP159: USB Micro B; USB-B-MICRO-SMD_V03
JP2, JP3, JP6, JP8, JP10, JP12, JP14, JP16, JP18, JP20, JP22, JP24, JP26, JP28, JP30, JP32, JP34, JP36, JP38, JP40, JP42, JP44, JP46, JP48, JP50, JP52, JP54, JP56, JP58, JP60, JP62, JP64, JP66, JP68, JP70, JP72, JP74, JP76, JP78, JP80, JP82, JP84, JP86, JP88, JP90, JP92, JP94, JP96, JP98, JP100, JP102, JP104, JP106, JP108, JP110, JP112, JP114, JP116, JP118, JP120, JP122, JP124, JP126, JP128, JP130, JP132, JP134, JP136, JP138, JP140, JP142, JP144, JP146, JP148, JP150, JP152, JP154, JP156, JP158, JP160: M02PTH; 1X02
LOGO1, LOGO4, LOGO7, LOGO10, LOGO13, LOGO16, LOGO19, LOGO22, LOGO25, LOGO28, LOGO31, LOGO34, LOGO37, LOGO40, LOGO43, LOGO46, LOGO49, LOGO52, LOGO55, LOGO58, LOGO61, LOGO64, LOGO67, LOGO70, LOGO73, LOGO76, LOGO79, LOGO82, LOGO85, LOGO88, LOGO91, LOGO94, LOGO97, LOGO100, LOGO103, LOGO106, LOGO109, LOGO112, LOGO115, LOGO118, LOGO121, LOGO124, LOGO127, LOGO130, LOGO133, LOGO136, LOGO139, LOGO142, LOGO145, LOGO148, LOGO151, LOGO154, LOGO157, LOGO160, LOGO163, LOGO166, LOGO169, LOGO172, LOGO175, LOGO178, LOGO181, LOGO184, LOGO187, LOGO190, LOGO193, LOGO196, LOGO199, LOGO202, LOGO205, LOGO208, LOGO211, LOGO214, LOGO217, LOGO220, LOGO223, LOGO226, LOGO229, LOGO232, LOGO235, LOGO238: SFE_LOGO_NAME.1_INCH; SFE_LOGO_NAME_.1
LOGO2, LOGO6, LOGO9, LOGO12, LOGO15, LOGO18, LOGO21, LOGO24, LOGO27, LOGO30, LOGO33, LOGO36, LOGO39, LOGO42, LOGO45, LOGO48, LOGO51, LOGO54, LOGO57, LOGO60, LOGO63, LOGO66, LOGO69, LOGO72, LOGO75, LOGO78, LOGO81, LOGO84, LOGO87, LOGO90, LOGO93, LOGO96, LOGO99, LOGO102, LOGO105, LOGO108, LOGO111, LOGO114, LOGO117, LOGO120, LOGO123, LOGO126, LOGO129, LOGO132, LOGO135, LOGO138, LOGO141, LOGO144, LOGO147, LOGO150, LOGO153, LOGO156, LOGO159, LOGO162, LOGO165, LOGO168, LOGO171, LOGO174, LOGO177, LOGO180, LOGO183, LOGO186, LOGO189, LOGO192, LOGO195, LOGO198, LOGO201, LOGO204, LOGO207, LOGO210, LOGO213, LOGO216, LOGO219, LOGO222, LOGO225, LOGO228, LOGO231, LOGO234, LOGO237, LOGO240: SFE_LOGO_FLAME.2_INCH; SFE_LOGO_FLAME_.2
LOGO3, LOGO5, LOGO8, LOGO11, LOGO14, LOGO17, LOGO20, LOGO23, LOGO26, LOGO29, LOGO32, LOGO35, LOGO38, LOGO41, LOGO44, LOGO47, LOGO50, LOGO53, LOGO56, LOGO59, LOGO62, LOGO65, LOGO68, LOGO71, LOGO74, LOGO77, LOGO80, LOGO83, LOGO86, LOGO89, LOGO92, LOGO95, LOGO98, LOGO101, LOGO104, LOGO107, LOGO110, LOGO113, LOGO116, LOGO119, LOGO122, LOGO125, LOGO128, LOGO131, LOGO134, LOGO137, LOGO140, LOGO143, LOGO146, LOGO149, LOGO152, LOGO155, LOGO158, LOGO161, LOGO164, LOGO167, LOGO170, LOGO173, LOGO176, LOGO179, LOGO182, LOGO185, LOGO188, LOGO191, LOGO194, LOGO197, LOGO200, LOGO203, LOGO206, LOGO209, LOGO212, LOGO215, LOGO218, LOGO221, LOGO224, LOGO227, LOGO230, LOGO233, LOGO236, LOGO239: OSHW-LOGOS; OSHW-LOGO-S
R1, R2, R3, R5, R6, R7, R9, R10, R11, R12, R14, R15, R16, R17, R19, R20, R21, R22, R24, R25, R26, R27, R29, R30, R31, R32, R34, R35, R36, R37, R39, R40, R41, R42, R44, R45, R46, R47, R49, R50, R51, R52, R54, R55, R56, R57, R59, R60, R61, R62, R64, R65, R66, R67, R69, R70, R71, R72, R74, R75, R76, R77, R79, R80, R81, R82, R84, R85, R86, R87, R89, R90, R91, R92, R94, R95, R96, R97, R99, R100, R101, R102, R104, R105, R106, R107, R109, R110, R111, R112, R114, R115, R116, R117, R119, R120, R121, R122, R124, R125, R126, R127, R129, R130, R131, R132, R134, R135, R136, R137, R139, R140, R141, R142, R144, R145, R146, R147, R149, R150, R151, R152, R154, R155, R156, R157, R159, R160, R161, R162, R164, R165, R166, R167, R169, R170, R171, R172, R174, R175, R176, R177, R179, R180, R181, R182, R184, R185, R186, R187, R189, R190, R191, R192, R194, R195, R196, R197, R199, R200, R201, R202, R204, R205, R206, R207, R209, R210, R211, R212, R214, R215, R216, R217, R219, R220, R221, R222, R224, R225, R226, R227, R229, R230, R231, R232, R234, R235, R236, R237, R239, R240, R241, R242, R244, R245, R246, R247, R249, R250, R251, R252, R254, R255, R256, R257, R259, R260, R261, R262, R264, R265, R266, R267, R269, R270, R271, R272, R274, R275, R276, R277, R279, R280, R281, R282, R284, R285, R286, R287, R289, R290, R291, R292, R294, R295, R296, R297, R299, R300, R301, R302, R304, R305, R306, R307, R309, R310, R311, R312, R314, R315, R316, R317, R319, R320, R321, R322, R324, R325, R326, R327, R329, R330, R331, R332, R334, R335, R336, R337, R339, R340, R341, R342, R344, R345, R346, R347, R349, R350, R351, R352, R354, R355, R356, R357, R359, R360, R361, R362, R364, R365, R366, R367, R369, R370, R371, R372, R374, R375, R376, R377, R379, R380, R381, R382, R384, R385, R386, R387, R389, R390, R391, R392, R394, R395, R396, R397, R399, R400: 1K; 0603-RES
R4, R8, R13, R18, R23, R28, R33, R38, R43, R48, R53, R58, R63, R68, R73, R78, R83, R88, R93, R98, R103, R108, R113, R118, R123, R128, R133, R138, R143, R148, R153, R158, R163, R168, R173, R178, R183, R188, R193, R198, R203, R208, R213, R218, R223, R228, R233, R238, R243, R248, R253, R258, R263, R268, R273, R278, R283, R288, R293, R298, R303, R308, R313, R318, R323, R328, R333, R338, R343, R348, R353, R358, R363, R368, R373, R378, R383, R388, R393, R398: 10K; 0603-RES
SJ1, SJ2, SJ3, SJ4, SJ5, SJ6, SJ7, SJ8, SJ9, SJ10, SJ11, SJ12, SJ13, SJ14, SJ15, SJ16, SJ17, SJ18, SJ19, SJ20, SJ21, SJ22, SJ23, SJ24, SJ25, SJ26, SJ27, SJ28, SJ29, SJ30, SJ31, SJ32, SJ33, SJ34, SJ35, SJ36, SJ37, SJ38, SJ39, SJ40, SJ41, SJ42, SJ43, SJ44, SJ45, SJ46, SJ47, SJ48, SJ49, SJ50, SJ51, SJ52, SJ53, SJ54, SJ55, SJ56, SJ57, SJ58, SJ59, SJ60, SJ61, SJ62, SJ63, SJ64, SJ65, SJ66, SJ67, SJ68, SJ69, SJ70, SJ71, SJ72, SJ73, SJ74, SJ75, SJ76, SJ77, SJ78, SJ79, SJ80: JUMPER-PAD-3-2OF3_NC_BY_PASTE; PAD-JUMPER-3-2OF3_NC_BY_PASTE_YES_SILK_FULL_BOX
U1, U5, U8, U11, U14, U17, U20, U23, U26, U29, U32, U35, U38, U41, U44, U47, U50, U53, U56, U59, U62, U65, U68, U71, U74, U77, U80, U83, U86, U89, U92, U95, U98, U101, U104, U107, U110, U113, U116, U119, U122, U125, U128, U131, U134, U137, U140, U143, U146, U149, U152, U155, U158, U161, U164, U167, U170, U173, U176, U179, U182, U185, U188, U191, U194, U197, U200, U203, U206, U209, U212, U215, U218, U221, U224, U227, U230, U233, U236, U239: FT232RLSSOP; SSOP28DB
U2, U6, U9, U12, U15, U18, U21, U24, U27, U30, U33, U36, U39, U42, U45, U48, U51, U54, U57, U60, U63, U66, U69, U72, U75, U78, U81, U84, U87, U90, U93, U96, U99, U102, U105, U108, U111, U114, U117, U120, U123, U126, U129, U132, U135, U138, U141, U144, U147, U150, U153, U156, U159, U162, U165, U168, U171, U174, U177, U180, U183, U186, U189, U192, U195, U198, U201, U204, U207, U210, U213, U216, U219, U222, U225, U228, U231, U234, U237, U240: MIC5219 3.3V; SOT23-5
U3, U4, U7, U10, U13, U16, U19, U22, U25, U28, U31, U34, U37, U40, U43, U46, U49, U52, U55, U58, U61, U64, U67, U70, U73, U76, U79, U82, U85, U88, U91, U94, U97, U100, U103, U106, U109, U112, U115, U118, U121, U124, U127, U130, U133, U136, U139, U142, U145, U148, U151, U154, U157, U160, U163, U166, U169, U172, U175, U178, U181, U184, U187, U190, U193, U196, U199, U202, U205, U208, U211, U214, U217, U220, U223, U226, U229, U232, U235, U238: TS3USB221A; QFN-10-RSE
U$1, U$2, U$3, U$4, U$5, U$6, U$7, U$8, U$9, U$10, U$11, U$12, U$13, U$14, U$15, U$16, U$17, U$18, U$19, U$20, U$21, U$22, U$23, U$24, U$25, U$26, U$27, U$28, U$29, U$30, U$31, U$32, U$33, U$34, U$35, U$36, U$37, U$38, U$39, U$40, U$41, U$42, U$43, U$44, U$45, U$46, U$47, U$48, U$49, U$50, U$51, U$52, U$53, U$54, U$55, U$56, U$57, U$58, U$59, U$60, U$61, U$62, U$63, U$64, U$65, U$66, U$67, U$68, U$69, U$70, U$71, U$72, U$73, U$74, U$75, U$76, U$77, U$78, U$79, U$80: SMART_BASIC_LOGO

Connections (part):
3.3V: C3.A, C5.1, C6.1, R1.2, R2.2, SJ1.1, U2.5, U3.10
3.3V1: C8.A, C10.1, C12.1, R6.2, R7.2, SJ2.1, U4.10, U6.5
3.3V2: C14.A, C16.1, C18.1, R11.2, R12.2, SJ3.1, U7.10, U9.5
3.3V3: C20.A, C22.1, C24.1, R16.2, R17.2, SJ4.1, U10.10, U12.5
3.3V4: C26.A, C28.1, C30.1, R21.2, R22.2, SJ5.1, U13.10, U15.5
3.3V5: C32.A, C34.1, C36.1, R26.2, R27.2, SJ6.1, U16.10, U18.5
3.3V6: C38.A, C40.1, C42.1, R31.2, R32.2, SJ7.1, U19.10, U21.5
3.3V7: C44.A, C46.1, C48.1, R36.2, R37.2, SJ8.1, U22.10, U24.5
3.3V8: C50.A, C52.1, C54.1, R41.2, R42.2, SJ9.1, U25.10, U27.5
3.3V9: C56.A, C58.1, C60.1, R46.2, R47.2, SJ10.1, U28.10, U30.5
3.3V10: C62.A, C64.1, C66.1, R51.2, R52.2, SJ11.1, U31.10, U33.5
3.3V11: C68.A, C70.1, C72.1, R56.2, R57.2, SJ12.1, U34.10, U36.5
3.3V12: C74.A, C76.1, C78.1, R61.2, R62.2, SJ13.1, U37.10, U39.5
3.3V13: C80.A, C82.1, C84.1, R66.2, R67.2, SJ14.1, U40.10, U42.5
3.3V14: C86.A, C88.1, C90.1, R71.2, R72.2, SJ15.1, U43.10, U45.5
3.3V15: C92.A, C94.1, C96.1, R76.2, R77.2, SJ16.1, U46.10, U48.5
3.3V16: C98.A, C100.1, C102.1, R81.2, R82.2, SJ17.1, U49.10, U51.5
3.3V17: C104.A, C106.1, C108.1, R86.2, R87.2, SJ18.1, U52.10, U54.5
3.3V18: C110.A, C112.1, C114.1, R91.2, R92.2, SJ19.1, U55.10, U57.5
3.3V19: C116.A, C118.1, C120.1, R96.2, R97.2, SJ20.1, U58.10, U60.5
3.3V20: C122.A, C124.1, C126.1, R101.2, R102.2, SJ21.1, U61.10, U63.5
3.3V21: C128.A, C130.1, C132.1, R106.2, R107.2, SJ22.1, U64.10, U66.5
3.3V22: C134.A, C136.1, C138.1, R111.2, R112.2, SJ23.1, U67.10, U69.5
3.3V23: C140.A, C142.1, C144.1, R116.2, R117.2, SJ24.1, U70.10, U72.5
3.3V24: C146.A, C148.1, C150.1, R121.2, R122.2, SJ25.1, U73.10, U75.5
3.3V25: C152.A, C154.1, C156.1, R126.2, R127.2, SJ26.1, U76.10, U78.5
3.3V26: C158.A, C160.1, C162.1, R131.2, R132.2, SJ27.1, U79.10, U81.5
3.3V27: C164.A, C166.1, C168.1, R136.2, R137.2, SJ28.1, U82.10, U84.5
3.3V28: C170.A, C172.1, C174.1, R141.2, R142.2, SJ29.1, U85.10, U87.5
3.3V29: C176.A, C178.1, C180.1, R146.2, R147.2, SJ30.1, U88.10, U90.5
3.3V30: C182.A, C184.1, C186.1, R151.2, R152.2, SJ31.1, U91.10, U93.5
3.3V31: C188.A, C190.1, C192.1, R156.2, R157.2, SJ32.1, U94.10, U96.5
3.3V32: C194.A, C196.1, C198.1, R161.2, R162.2, SJ33.1, U97.10, U99.5
3.3V33: C200.A, C202.1, C204.1, R166.2, R167.2, SJ34.1, U100.10, U102.5
3.3V34: C206.A, C208.1, C210.1, R171.2, R172.2, SJ35.1, U103.10, U105.5
3.3V35: C212.A, C214.1, C216.1, R176.2, R177.2, SJ36.1, U106.10, U108.5
3.3V36: C218.A, C220.1, C222.1, R181.2, R182.2, SJ37.1, U109.10, U111.5
3.3V37: C224.A, C226.1, C228.1, R186.2, R187.2, SJ38.1, U112.10, U114.5
3.3V38: C230.A, C232.1, C234.1, R191.2, R192.2, SJ39.1, U115.10, U117.5
3.3V39: C236.A, C238.1, C240.1, R196.2, R197.2, SJ40.1, U118.10, U120.5
3.3V40: C242.A, C244.1, C246.1, R201.2, R202.2, SJ41.1, U121.10, U123.5
3.3V41: C248.A, C250.1, C252.1, R206.2, R207.2, SJ42.1, U124.10, U126.5
3.3V42: C254.A, C256.1, C258.1, R211.2, R212.2, SJ43.1, U127.10, U129.5
3.3V43: C260.A, C262.1, C264.1, R216.2, R217.2, SJ44.1, U130.10, U132.5
3.3V44: C266.A, C268.1, C270.1, R221.2, R222.2, SJ45.1, U133.10, U135.5
3.3V45: C272.A, C274.1, C276.1, R226.2, R227.2, SJ46.1, U136.10, U138.5
3.3V46: C278.A, C280.1, C282.1, R231.2, R232.2, SJ47.1, U139.10, U141.5
3.3V47: C284.A, C286.1, C288.1, R236.2, R237.2, SJ48.1, U142.10, U144.5
3.3V48: C290.A, C292.1, C294.1, R241.2, R242.2, SJ49.1, U145.10, U147.5
3.3V49: C296.A, C298.1, C300.1, R246.2, R247.2, SJ50.1, U148.10, U150.5
3.3V50: C302.A, C304.1, C306.1, R251.2, R252.2, SJ51.1, U151.10, U153.5
3.3V51: C308.A, C310.1, C312.1, R256.2, R257.2, SJ52.1, U154.10, U156.5
3.3V52: C314.A, C316.1, C318.1, R261.2, R262.2, SJ53.1, U157.10, U159.5
3.3V53: C320.A, C322.1, C324.1, R266.2, R267.2, SJ54.1, U160.10, U162.5
3.3V54: C326.A, C328.1, C330.1, R271.2, R272.2, SJ55.1, U163.10, U165.5
3.3V55: C332.A, C334.1, C336.1, R276.2, R277.2, SJ56.1, U166.10, U168.5
3.3V56: C338.A, C340.1, C342.1, R281.2, R282.2, SJ57.1, U169.10, U171.5
3.3V57: C344.A, C346.1, C348.1, R286.2, R287.2, SJ58.1, U172.10, U174.5
3.3V58: C350.A, C352.1, C354.1, R291.2, R292.2, SJ59.1, U175.10, U177.5
3.3V59: C356.A, C358.1, C360.1, R296.2, R297.2, SJ60.1, U178.10, U180.5
3.3V60: C362.A, C364.1, C366.1, R301.2, R302.2, SJ61.1, U181.10, U183.5
3.3V61: C368.A, C370.1, C372.1, R306.2, R307.2, SJ62.1, U184.10, U186.5
3.3V62: C374.A, C376.1, C378.1, R311.2, R312.2, SJ63.1, U187.10, U189.5
3.3V63: C380.A, C382.1, C384.1, R316.2, R317.2, SJ64.1, U190.10, U192.5
3.3V64: C386.A, C388.1, C390.1, R321.2, R322.2, SJ65.1, U193.10, U195.5
3.3V65: C392.A, C394.1, C396.1, R326.2, R327.2, SJ66.1, U196.10, U198.5
3.3V66: C398.A, C400.1, C402.1, R331.2, R332.2, SJ67.1, U199.10, U201.5
3.3V67: C404.A, C406.1, C408.1, R336.2, R337.2, SJ68.1, U202.10, U204.5
3.3V68: C410.A, C412.1, C414.1, R341.2, R342.2, SJ69.1, U205.10, U207.5
3.3V69: C416.A, C418.1, C420.1, R346.2, R347.2, SJ70.1, U208.10, U210.5
3.3V70: C422.A, C424.1, C426.1, R351.2, R352.2, SJ71.1, U211.10, U213.5
3.3V71: C428.A, C430.1, C432.1, R356.2, R357.2, SJ72.1, U214.10, U216.5
3.3V72: C434.A, C436.1, C438.1, R361.2, R362.2, SJ73.1, U217.10, U219.5
3.3V73: C440.A, C442.1, C444.1, R366.2, R367.2, SJ74.1, U220.10, U222.5
3.3V74: C446.A, C448.1, C450.1, R371.2, R372.2, SJ75.1, U223.10, U225.5
3.3V75: C452.A, C454.1, C456.1, R376.2, R377.2, SJ76.1, U226.10, U228.5
3.3V76: C458.A, C460.1, C462.1, R381.2, R382.2, SJ77.1, U229.10, U231.5
3.3V77: C464.A, C466.1, C468.1, R386.2, R387.2, SJ78.1, U232.10, U234.5
3.3V78: C470.A, C472.1, C474.1, R391.2, R392.2, SJ79.1, U235.10, U237.5
3.3V79: C476.A, C478.1, C480.1, R396.2, R397.2, SJ80.1, U238.10, U240.5
5V: C1.A, C2.1, JP4.VBUS1, SJ1.3, U1.20, U2.1, U2.3
5V1: C7.1, C11.A, JP1.VBUS1, SJ2.3, U5.20, U6.1, U6.3
5V2: C13.1, C17.A, JP5.VBUS1, SJ3.3, U8.20, U9.1, U9.3
5V3: C19.1, C23.A, JP7.VBUS1, SJ4.3, U11.20, U12.1, U12.3
5V4: C25.1, C29.A, JP9.VBUS1, SJ5.3, U14.20, U15.1, U15.3
5V5: C31.1, C35.A, JP11.VBUS1, SJ6.3, U17.20, U18.1, U18.3
5V6: C37.1, C41.A, JP13.VBUS1, SJ7.3, U20.20, U21.1, U21.3
5V7: C43.1, C47.A, JP15.VBUS1, SJ8.3, U23.20, U24.1, U24.3
5V8: C49.1, C53.A, JP17.VBUS1, SJ9.3, U26.20, U27.1, U27.3
5V9: C55.1, C59.A, JP19.VBUS1, SJ10.3, U29.20, U30.1, U30.3
5V10: C61.1, C65.A, JP21.VBUS1, SJ11.3, U32.20, U33.1, U33.3
5V11: C67.1, C71.A, JP23.VBUS1, SJ12.3, U35.20, U36.1, U36.3
5V12: C73.1, C77.A, JP25.VBUS1, SJ13.3, U38.20, U39.1, U39.3
5V13: C79.1, C83.A, JP27.VBUS1, SJ14.3, U41.20, U42.1, U42.3
5V14: C85.1, C89.A, JP29.VBUS1, SJ15.3, U44.20, U45.1, U45.3
5V15: C91.1, C95.A, JP31.VBUS1, SJ16.3, U47.20, U48.1, U48.3
5V16: C97.1, C101.A, JP33.VBUS1, SJ17.3, U50.20, U51.1, U51.3
5V17: C103.1, C107.A, JP35.VBUS1, SJ18.3, U53.20, U54.1, U54.3
5V18: C109.1, C113.A, JP37.VBUS1, SJ19.3, U56.20, U57.1, U57.3
5V19: C115.1, C119.A, JP39.VBUS1, SJ20.3, U59.20, U60.1, U60.3
5V20: C121.1, C125.A, JP41.VBUS1, SJ21.3, U62.20, U63.1, U63.3
5V21: C127.1, C131.A, JP43.VBUS1, SJ22.3, U65.20, U66.1, U66.3
5V22: C133.1, C137.A, JP45.VBUS1, SJ23.3, U68.20, U69.1, U69.3
5V23: C139.1, C143.A, JP47.VBUS1, SJ24.3, U71.20, U72.1, U72.3
5V24: C145.1, C149.A, JP49.VBUS1, SJ25.3, U74.20, U75.1, U75.3
5V25: C151.1, C155.A, JP51.VBUS1, SJ26.3, U77.20, U78.1, U78.3
5V26: C157.1, C161.A, JP53.VBUS1, SJ27.3, U80.20, U81.1, U81.3
5V27: C163.1, C167.A, JP55.VBUS1, SJ28.3, U83.20, U84.1, U84.3
5V28: C169.1, C173.A, JP57.VBUS1, SJ29.3, U86.20, U87.1, U87.3
5V29: C175.1, C179.A, JP59.VBUS1, SJ30.3, U89.20, U90.1, U90.3
5V30: C181.1, C185.A, JP61.VBUS1, SJ31.3, U92.20, U93.1, U93.3
5V31: C187.1, C191.A, JP63.VBUS1, SJ32.3, U95.20, U96.1, U96.3
5V32: C193.1, C197.A, JP65.VBUS1, SJ33.3, U98.20, U99.1, U99.3
5V33: C199.1, C203.A, JP67.VBUS1, SJ34.3, U101.20, U102.1, U102.3
5V34: C205.1, C209.A, JP69.VBUS1, SJ35.3, U104.20, U105.1, U105.3
5V35: C211.1, C215.A, JP71.VBUS1, SJ36.3, U107.20, U108.1, U108.3
5V36: C217.1, C221.A, JP73.VBUS1, SJ37.3, U110.20, U111.1, U111.3
5V37: C223.1, C227.A, JP75.VBUS1, SJ38.3, U113.20, U114.1, U114.3
5V38: C229.1, C233.A, JP77.VBUS1, SJ39.3, U116.20, U117.1, U117.3
5V39: C235.1, C239.A, JP79.VBUS1, SJ40.3, U119.20, U120.1, U120.3
5V40: C241.1, C245.A, JP81.VBUS1, SJ41.3, U122.20, U123.1, U123.3
5V41: C247.1, C251.A, JP83.VBUS1, SJ42.3, U125.20, U126.1, U126.3
5V42: C253.1, C257.A, JP85.VBUS1, SJ43.3, U128.20, U129.1, U129.3
5V43: C259.1, C263.A, JP87.VBUS1, SJ44.3, U131.20, U132.1, U132.3
5V44: C265.1, C269.A, JP89.VBUS1, SJ45.3, U134.20, U135.1, U135.3
5V45: C271.1, C275.A, JP91.VBUS1, SJ46.3, U137.20, U138.1, U138.3
5V46: C277.1, C281.A, JP93.VBUS1, SJ47.3, U140.20, U141.1, U141.3
5V47: C283.1, C287.A, JP95.VBUS1, SJ48.3, U143.20, U144.1, U144.3
5V48: C289.1, C293.A, JP97.VBUS1, SJ49.3, U146.20, U147.1, U147.3
5V49: C295.1, C299.A, JP99.VBUS1, SJ50.3, U149.20, U150.1, U150.3
5V50: C301.1, C305.A, JP101.VBUS1, SJ51.3, U152.20, U153.1, U153.3
5V51: C307.1, C311.A, JP103.VBUS1, SJ52.3, U155.20, U156.1, U156.3
5V52: C313.1, C317.A, JP105.VBUS1, SJ53.3, U158.20, U159.1, U159.3
5V53: C319.1, C323.A, JP107.VBUS1, SJ54.3, U161.20, U162.1, U162.3
5V54: C325.1, C329.A, JP109.VBUS1, SJ55.3, U164.20, U165.1, U165.3
5V55: C331.1, C335.A, JP111.VBUS1, SJ56.3, U167.20, U168.1, U168.3
5V56: C337.1, C341.A, JP113.VBUS1, SJ57.3, U170.20, U171.1, U171.3
5V57: C343.1, C347.A, JP115.VBUS1, SJ58.3, U173.20, U174.1, U174.3
5V58: C349.1, C353.A, JP117.VBUS1, SJ59.3, U176.20, U177.1, U177.3
5V59: C355.1, C359.A, JP119.VBUS1, SJ60.3, U179.20, U180.1, U180.3
5V60: C361.1, C365.A, JP121.VBUS1, SJ61.3, U182.20, U183.1, U183.3
5V61: C367.1, C371.A, JP123.VBUS1, SJ62.3, U185.20, U186.1, U186.3
5V62: C373.1, C377.A, JP125.VBUS1, SJ63.3, U188.20, U189.1, U189.3
5V63: C379.1, C383.A, JP127.VBUS1, SJ64.3, U191.20, U192.1, U192.3
5V64: C385.1, C389.A, JP129.VBUS1, SJ65.3, U194.20, U195.1, U195.3
5V65: C391.1, C395.A, JP131.VBUS1, SJ66.3, U197.20, U198.1, U198.3
5V66: C397.1, C401.A, JP133.VBUS1, SJ67.3, U200.20, U201.1, U201.3
5V67: C403.1, C407.A, JP135.VBUS1, SJ68.3, U203.20, U204.1, U204.3
5V68: C409.1, C413.A, JP137.VBUS1, SJ69.3, U206.20, U207.1, U207.3
5V69: C415.1, C419.A, JP139.VBUS1, SJ70.3, U209.20, U210.1, U210.3
5V70: C421.1, C425.A, JP141.VBUS1, SJ71.3, U212.20, U213.1, U213.3
5V71: C427.1, C431.A, JP143.VBUS1, SJ72.3, U215.20, U216.1, U216.3
5V72: C433.1, C437.A, JP145.VBUS1, SJ73.3, U218.20, U219.1, U219.3
5V73: C439.1, C443.A, JP147.VBUS1, SJ74.3, U221.20, U222.1, U222.3
5V74: C445.1, C449.A, JP149.VBUS1, SJ75.3, U224.20, U225.1, U225.3
5V75: C451.1, C455.A, JP151.VBUS1, SJ76.3, U227.20, U228.1, U228.3
5V76: C457.1, C461.A, JP153.VBUS1, SJ77.3, U230.20, U231.1, U231.3
5V77: C463.1, C467.A, JP155.VBUS1, SJ78.3, U233.20, U234.1, U234.3
5V78: C469.1, C473.A, JP157.VBUS1, SJ79.3, U236.20, U237.1, U237.3
5V79: C475.1, C479.A, JP159.VBUS1, SJ80.3, U239.20, U240.1, U240.3
!OE: JP2.1, R4.1, U3.6
!OE1: JP3.1, R8.1, U4.6
!OE2: JP6.1, R13.1, U7.6
!OE3: JP8.1, R18.1, U10.6
!OE4: JP10.1, R23.1, U13.6
!OE5: JP12.1, R28.1, U16.6
!OE6: JP14.1, R33.1, U19.6
!OE7: JP16.1, R38.1, U22.6
!OE8: JP18.1, R43.1, U25.6
!OE9: JP20.1, R48.1, U28.6
!OE10: JP22.1, R53.1, U31.6
!OE11: JP24.1, R58.1, U34.6
!OE12: JP26.1, R63.1, U37.6
!OE13: JP28.1, R68.1, U40.6
!OE14: JP30.1, R73.1, U43.6
!OE15: JP32.1, R78.1, U46.6
!OE16: JP34.1, R83.1, U49.6
!OE17: JP36.1, R88.1, U52.6
!OE18: JP38.1, R93.1, U55.6
!OE19: JP40.1, R98.1, U58.6
!OE20: JP42.1, R103.1, U61.6
!OE21: JP44.1, R108.1, U64.6
!OE22: JP46.1, R113.1, U67.6
!OE23: JP48.1, R118.1, U70.6
!OE24: JP50.1, R123.1, U73.6
!OE25: JP52.1, R128.1, U76.6
!OE26: JP54.1, R133.1, U79.6
!OE27: JP56.1, R138.1, U82.6
!OE28: JP58.1, R143.1, U85.6
!OE29: JP60.1, R148.1, U88.6
!OE30: JP62.1, R153.1, U91.6
!OE31: JP64.1, R158.1, U94.6
!OE32: JP66.1, R163.1, U97.6
!OE33: JP68.1, R168.1, U100.6
!OE34: JP70.1, R173.1, U103.6
!OE35: JP72.1, R178.1, U106.6
!OE36: JP74.1, R183.1, U109.6
!OE37: JP76.1, R188.1, U112.6
!OE38: JP78.1, R193.1, U115.6
!OE39: JP80.1, R198.1, U118.6
!OE40: JP82.1, R203.1, U121.6
!OE41: JP84.1, R208.1, U124.6
!OE42: JP86.1, R213.1, U127.6
!OE43: JP88.1, R218.1, U130.6
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

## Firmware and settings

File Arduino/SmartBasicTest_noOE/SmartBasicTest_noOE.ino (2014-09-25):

/****************************************************************
Example code demonstrating the use of the FTDI SmartBasic board.
The SmartBasic board is a serial data multiplexer which allows
a user to program an Arduino Pro, Pro Mini, Fio, or other board
without an on-board USB-to-serial bridge while keeping another
serial connected device connected to the Arduino's hardware
serial port.

This example uses a normal FTDI Basic board as the auxiliary
device; that board's serial port is opened in another terminal.

This code is beerware; if you use it, please buy me (or any other
SparkFun employee) a cold beverage next time you run into one of
us at the local.

25 Sep 2014- Mike Hord, SparkFun Electronics

Code developed in Arduino 1.0.5, on a 5V Arduino Pro board.
****************************************************************/

// Set up a few constants
    #define SEL 2  // When the SEL pin is held low, the data will be
                   //  routed to the PC via the USB-serial bridge.
                   //  That port is also the port used for programming
                   //  by the Arduino IDE. When in bootloading mode, a
                   //  pull-down resistor on the SmartBasic causes it
                   //  to remain in programming mode.
    
    #define ARDUINO_IDE   LOW  // Constants to make our routing change
    #define AUX_TERMINAL  HIGH //  more obvious. When the SEL pin is 
                               //  LOW, data is routed to the
                               //  programming port.
    
    void setup()
    {
      Serial.begin(115200);    // Set up the hardware serial port.
      
      pinMode(SEL, OUTPUT);    // Make the select line an output...
      digitalWrite(SEL, ARDUINO_IDE); // ...and connect the board to
                               //  the Arduino IDE's terminal.  
    }
    
    void loop()
    {
      // The loop just says "Hello" to the two terminals, over and
      //  over, forever. Note the use of the "flush()" function. If
      //  omitted, the Arduino will re-route the serial data before
      //  the transmission has been completed; flush() causes the
      //  Arduino to block until the serial data output buffer is
      //  empty. Failure to use flush() will result in data being
      //  sent to the wrong device, or to multiplexer changes during
      //  transmission which may cause framing errors or data
      //  corruption. *Always put in a flush() before you change
      //  destination devices or disable the output.*
      Serial.flush();
      digitalWrite(SEL, ARDUINO_IDE);
      Serial.println("Hello, Arduino IDE!");
      
      // Swap to the non-Arduino terminal and say hello.
      Serial.flush();
      digitalWrite(SEL, AUX_TERMINAL);
      Serial.println("Hello, auxilliary terminal!");
    
      Serial.flush();
    
      delay(500); // This is a rate-limiter only. The temptation to use
                  //  delay() instead of flush() is strong, but fight it.
                  //  If you use delay, you will *certainly* make a change
                  //  to the code which makes the original delay time too
                  //  short for the new serial data stream, resulting in
                  //  data corruption. flush() will *always* be the right
                  //  length.
    }

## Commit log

2014-05-19 Incorporate changes from review
    [FTDI_SmartBasic.brd, FTDI_SmartBasic.sch]
2014-06-24 2nd round protos - add vias to strain relief pads on connector - flip the client connector - remove the USB indicator LED and change other LED label - change silk from JP1 and JP3 to HOST and CLIENT
    [FTDI_SmartBasic.brd, FTDI_SmartBasic.sch]
2014-06-24 Minor changes from review
    [FTDI_SmartBasic.brd, FTDI_SmartBasic.sch]
2014-07-18 Ready for review for reds
    [FTDI_SmartBasic.brd, FTDI_SmartBasic.sch]
2014-07-21 Ready for release.
    [FTDI_SmartBasic.brd]
2014-07-24 added local fiducials
    [FTDI_SmartBasic.brd, FTDI_SmartBasic.sch]
2014-07-24 created panels
    both regular, and giant
    [FTDI_SmartBasic-GiantPanel-v10.brd, FTDI_SmartBasic-Panel-v10.brd]
2014-08-21 Fixed bottom silk, rev to 11
    [FTDI_SmartBasic.brd, FTDI_SmartBasic.sch]
2014-08-21 re-created panel with correct silk
    [FTDI_SmartBasic-GiantPanel-v10a.brd, FTDI_SmartBasic-Panel-v10a.brd]
2014-08-21 changed file name to v11
    [FTDI_SmartBasic-GiantPanel-v11.brd, FTDI_SmartBasic-Panel-v11.brd]

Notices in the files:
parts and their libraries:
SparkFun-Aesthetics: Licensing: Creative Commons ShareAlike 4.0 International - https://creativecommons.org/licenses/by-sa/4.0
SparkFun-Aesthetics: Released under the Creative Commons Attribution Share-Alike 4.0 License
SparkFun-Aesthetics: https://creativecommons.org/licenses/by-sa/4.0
